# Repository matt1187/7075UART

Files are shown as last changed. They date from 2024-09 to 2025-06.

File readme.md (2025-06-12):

# Project  Solatron 7075 UART remote interface

History: Solartron 70755 GPIB Modul is useless (many people isn't capable to talking with GPIB modul) 
This is why, i make  MK-7075UART interface.
7075UART3
7075uart2

# PCB Revision History 
- MK-7075UART-000 improvement draft from  7075UART-000

# Feartures
- Talker/Listener mode
- Normal/exponent mode (10.123 VDC  / 1.0123E+1 VDC)
- 9600/38400/57600/115200 Baud select
- isolated RS232 interface
- SCPI & IEEE488.2 snytax 

# how to using of interface
- [howto (LINK)]

# Issues 
-  current no  remote function aviable

# Notes
- SSD1306 is optional. (actual firmware hasn't function for OLED)
- 74HCT165 on U11 is recommend,  (74LS165, you must modified PCB to adding of 1k Resistor on their output, otherwise, ISCP doesn't work)
- DC/DC converter should be soldered on bottom,  SW6 dip swith should attached with socket.
- U13, U14, U15 is optional (actual firmware doesn't support remote function, this ICs is for remote function )
- Diode D5 is recommend for pcb "engineering sample" for often reprogramming, while Solartron is turned off. Oterhwise, you can placed it with wire (or 0 ohm 2510 resistor)

# Bill of material
- [csv-file]
- [gerber-file]
- [3D-print-file]

# Firmware
- [atmega 8 firmware 0.5d]

# License
The project is free for non-commercial reproduction. Do not sell it on Ebay or other platforms for profit. Do not make a closed source derivative. Share your experiences and ideas with the community.

This work is licensed under a [Creative Commons Attribution-NonCommercial-ShareAlike 4.0 International License][cc-by-nc-sa].

[][cc-by-nc-sa]

[cc-by-nc-sa]: http://creativecommons.org/licenses/by-nc-sa/4.0/
[cc-by-nc-sa-image]: https://licensebuttons.net/l/by-nc-sa/4.0/88x31.png

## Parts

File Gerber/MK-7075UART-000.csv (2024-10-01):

Date: | Sa 14 Sep 2024 12:12:50 CEST
Tool: | Eeschema 6.0.11-2627ca5db0~126~ubuntu22.04.1
Component Count: | 66
Ref | Qnty | Value | Cmp name | Footprint | Supplier | Order-number
C1, C2, | 2 | 6p | C | Capacitor_SMD:C_0805_2012Metric | Mouser | 581-08055A6R0CAT2A
C3, C4, C5, C6, C7, C8, C10, C11, C12, C13, C14, C15, C20, C21, C22, C23, C24, C26, C27, | 19 | 100n | C | Capacitor_SMD:C_0805_2012Metric | Mouser | 581-08055C104K
C19, | 1 | 47µ 16V | C_Polarized | Capacitor_Tantalum_SMD:CP_EIA-6032-28_Kemet-C | Mouser | 80-T491C476M010
C25, C29, C30, | 3 | 10µ | C | Capacitor_SMD:C_0805_2012Metric | Mouser | 81-GRM21B71E106KE01L
C28, | 1 | 10n X2 | C | Capacitor_THT:C_Disc_D7.5mm_W5.0mm_P10.00mm | optional | optional
D1, D2, D3, D4 | 4 | 1N4818 | D | Diode_SMD:D_MiniMELF | Mouser | 637-LL4148
D5, | 1 | SHOTTKY | D | Diode_SMD:D_MELF | Mouser | 625-BYM13-40-E3/97 or 791-RMC1JPTE
F1, | 1 | RUEF90 | Polyfuse | Fuse:Fuse_Bourns_MF-RG300 | Mouser | 650-RUEF090
J1, | 1 | DB9_male_MountingHoles | DB9_Female_MountingHoles | Connector_Dsub:DSUB-9_Male_Vertical_P2.77x2.84mm_MountingHoles | Mouser | 649-D09P24A4GL00LF
J2, | 1 | ICSP | Conn_02x03_Odd_Even | Connector_PinHeader_2.54mm:PinHeader_2x03_P2.54mm_Vertical | Mouser | 571-5-146258-3
J4, | 1 | SSD1306 OLED Display | Conn_01x04_Female | Display:SSD1306 | don't place | don't place
JP3, | 1 |  | SolderJumper_2_Bridged | Jumper:SolderJumper-2_P1.3mm_Open_Pad1.0x1.5mm | don't place | don't place
L1, | 1 | L_Coupled_1243 | L_Coupled_1243 | Inductor_SMD:L_EPCOS_B82790 | Mouser | 871-B82790C225N265
Q1, | 1 | 16Mhz | Crystal | Crystal:Crystal_HC49-U_Vertical | Mouser | 815-ABL-16-B4Y
R1, R18, R19, | 3 | 1k | R | Resistor_SMD:R_0805_2012Metric | Mouser | 603-RC0805JR-071KL
R2, | 1 | 4.3k | R | Resistor_SMD:R_0805_2012Metric | Mouser | 603-RC0805JR-074K3L
R3, | 1 | 470 | R | Resistor_SMD:R_0805_2012Metric | Mouser | 603-RC0805JR-07470RL
R16, R17, | 2 | 392 | R | Resistor_SMD:R_0805_2012Metric | Mouser | 603-RC0201FR-07392RL
R20, R21, R22, R23, | 4 | 47k | R | Resistor_SMD:R_0805_2012Metric | Mouser | 603-RC0805JR-0747KL
SK1, | 1 | DB50_Male_MountingHoles | DB50_Male_MountingHoles-Connector | Connector_Dsub:DSUB-50-HD_Male_vertical | Mouser | 649-D50P24A4GL00LF
SW6, | 1 | config | SW_DIP_x04 | Package_DIP:DIP-8_W7.62mm | Mouser | 611-BD04AV
SW6-socket | 1 | config | SW_DIP_x04 | Package_DIP:DIP-8_W7.62mm | Mouser | 575-11041308410010
U1, | 1 | ATmega8-AU | ATmega8-AU-MCU_Microchip_ATmega | Package_QFP:TQFP-32_7x7mm_P0.8mm | Mouser | 556-ATMEGA8-16AU
U2, | 1 | 74LS164 | 74LS164-74xx | Package_SO:SOIC-14_3.9x8.7mm_P1.27mm | Mouser | 595-SN74LS164DR
U4, | 1 | 74LS157 | 74LS157 | Package_DIP:DIP-16_W7.62mm | Mouser | 595-SN74LS157N
U5, | 1 | 74LS189 | 74LS189-74xx | Package_DIP:DIP-16_W7.62mm | varios | SN74LS189
U8, | 1 | 74HCT00 | 74HCT00 | Package_SO:SOIC-14_3.9x8.7mm_P1.27mm | Mouser | 771-74HCT00D-T
U10, U11, | 2 | 74HCT165 | 74HCT165 | Package_SO:SOIC-16_3.9x9.9mm_P1.27mm | Mouser | 771-74HCT165D-T
U12, U13, U14, U15, | 4 | 74HCT595 | 74HCT595 | Package_SO:SOIC-16_3.9x9.9mm_P1.27mm | Mouser | 863-MC74HCT595ADG
U19, | 1 | IH0505S | IH0505S | Converter_DCDC:SIP-7 | Mouser | 710-177920514
U20, | 1 | MAX232A | MAX232 | Package_SO:SOIC-16_3.9x9.9mm_P1.27mm | Mouser | 511-ST3232EBDR or 700-MAX232ACWET
U21, U22, | 2 | HCPL-0600 | HCPL-0600 | Package_SO:SOIC-8_3.9x4.9mm_P1.27mm | Mouser | 630-HCPL-0600-000E

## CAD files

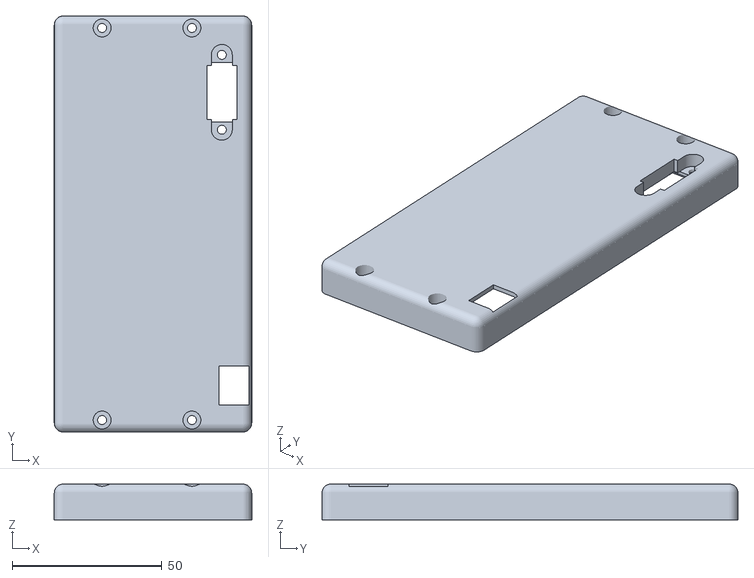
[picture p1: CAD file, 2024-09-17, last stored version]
top_wo_SCP.stl
66.0 x 139.0 x 12.0

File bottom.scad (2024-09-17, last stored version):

 $fn=32;
 
radius = 3; 
height=  12;
width = 66-radius-radius;
length = 123+16-radius-radius;


difference(){
translate([-3,-5,0])
   
    hull(){
            translate([0,0,0]){
            cylinder(r=radius,h=height+2);
            }
            translate([width,0,0]){
            cylinder(r=radius,h=height+2);
            }
            translate([0,length,0]){
            cylinder(r=radius,h=height+2);
            }
            translate([width,length,0]){
            cylinder(r=radius,h=height+2);
            }
        }
        
     //inner cutoff   
     translate([-0.5,-0.5,2])
        difference (){
        cube ([width+3.5, length-10+1,height]); 
     //DSUB 50 support
        cube ([20,74,4]);
     // below support       
        translate([54,26,0])
        cube ([10,123,height-2]); 
        translate([54,0,0])
        cube ([10,123,height-4]);     
      // rs232 support 
        translate([35,90,0])
        cube ([7,123,height-2]);         
        }
        
    //DSUB 50 cutoff   
        
    translate([9,6,0]){
    cylinder(r=4,h=4);
    cylinder(r=1.5,h=6);
    }       
      
    translate([9,6+61.1,0]){
    cylinder(r=4,h=4);   
    cylinder(r=1.5,h=6);   
    }   
    translate([9-13/2,6+(61.1-54)/2,0])
    cube ([13, 54,height]);
   
    translate([9-8/2,6,0])
    cube ([8, 61.1,4]);
    
    translate([1.5,6+(61.1-56)/2,5])
    cube ([15, 56,4]);
    
     // cutoff  for screw (rear of 7075)
    translate ([57,116,0])
    cylinder(r=4,h=3);
    
    translate ([-2.5,116,0])
    cylinder(r=4,h=3);
    
     // cutoff  for screw
    translate([-6,31,0])
    cube ([4, 10,height+2]);   
    
    // hole for screw 
    translate([10,-4,0])
    cylinder(r=1.5,h=20);   
    
    translate([10+30,-4,0])
    cylinder(r=1.5,h=20); 
    
    translate([10,-4+123+8,0])
    cylinder(r=1.5,h=20); 
    
    translate([10+30,-4+123+8,0])
    cylinder(r=1.5,h=20); 
  // hole for nuts  
   
    translate([10,-4,0])
    cylinder(r=3.3,h=5,$fn=6);  
     
    translate([10+30,-4,0])
    cylinder(r=3.3,h=5,$fn=6); 
    
    translate([10,-4+123+8,0])
    cylinder(r=3.3,h=5,$fn=6); 
    
    translate([10+30,-4+123+8,0])
    cylinder(r=3.3,h=5,$fn=6); 
    
   
        
    }

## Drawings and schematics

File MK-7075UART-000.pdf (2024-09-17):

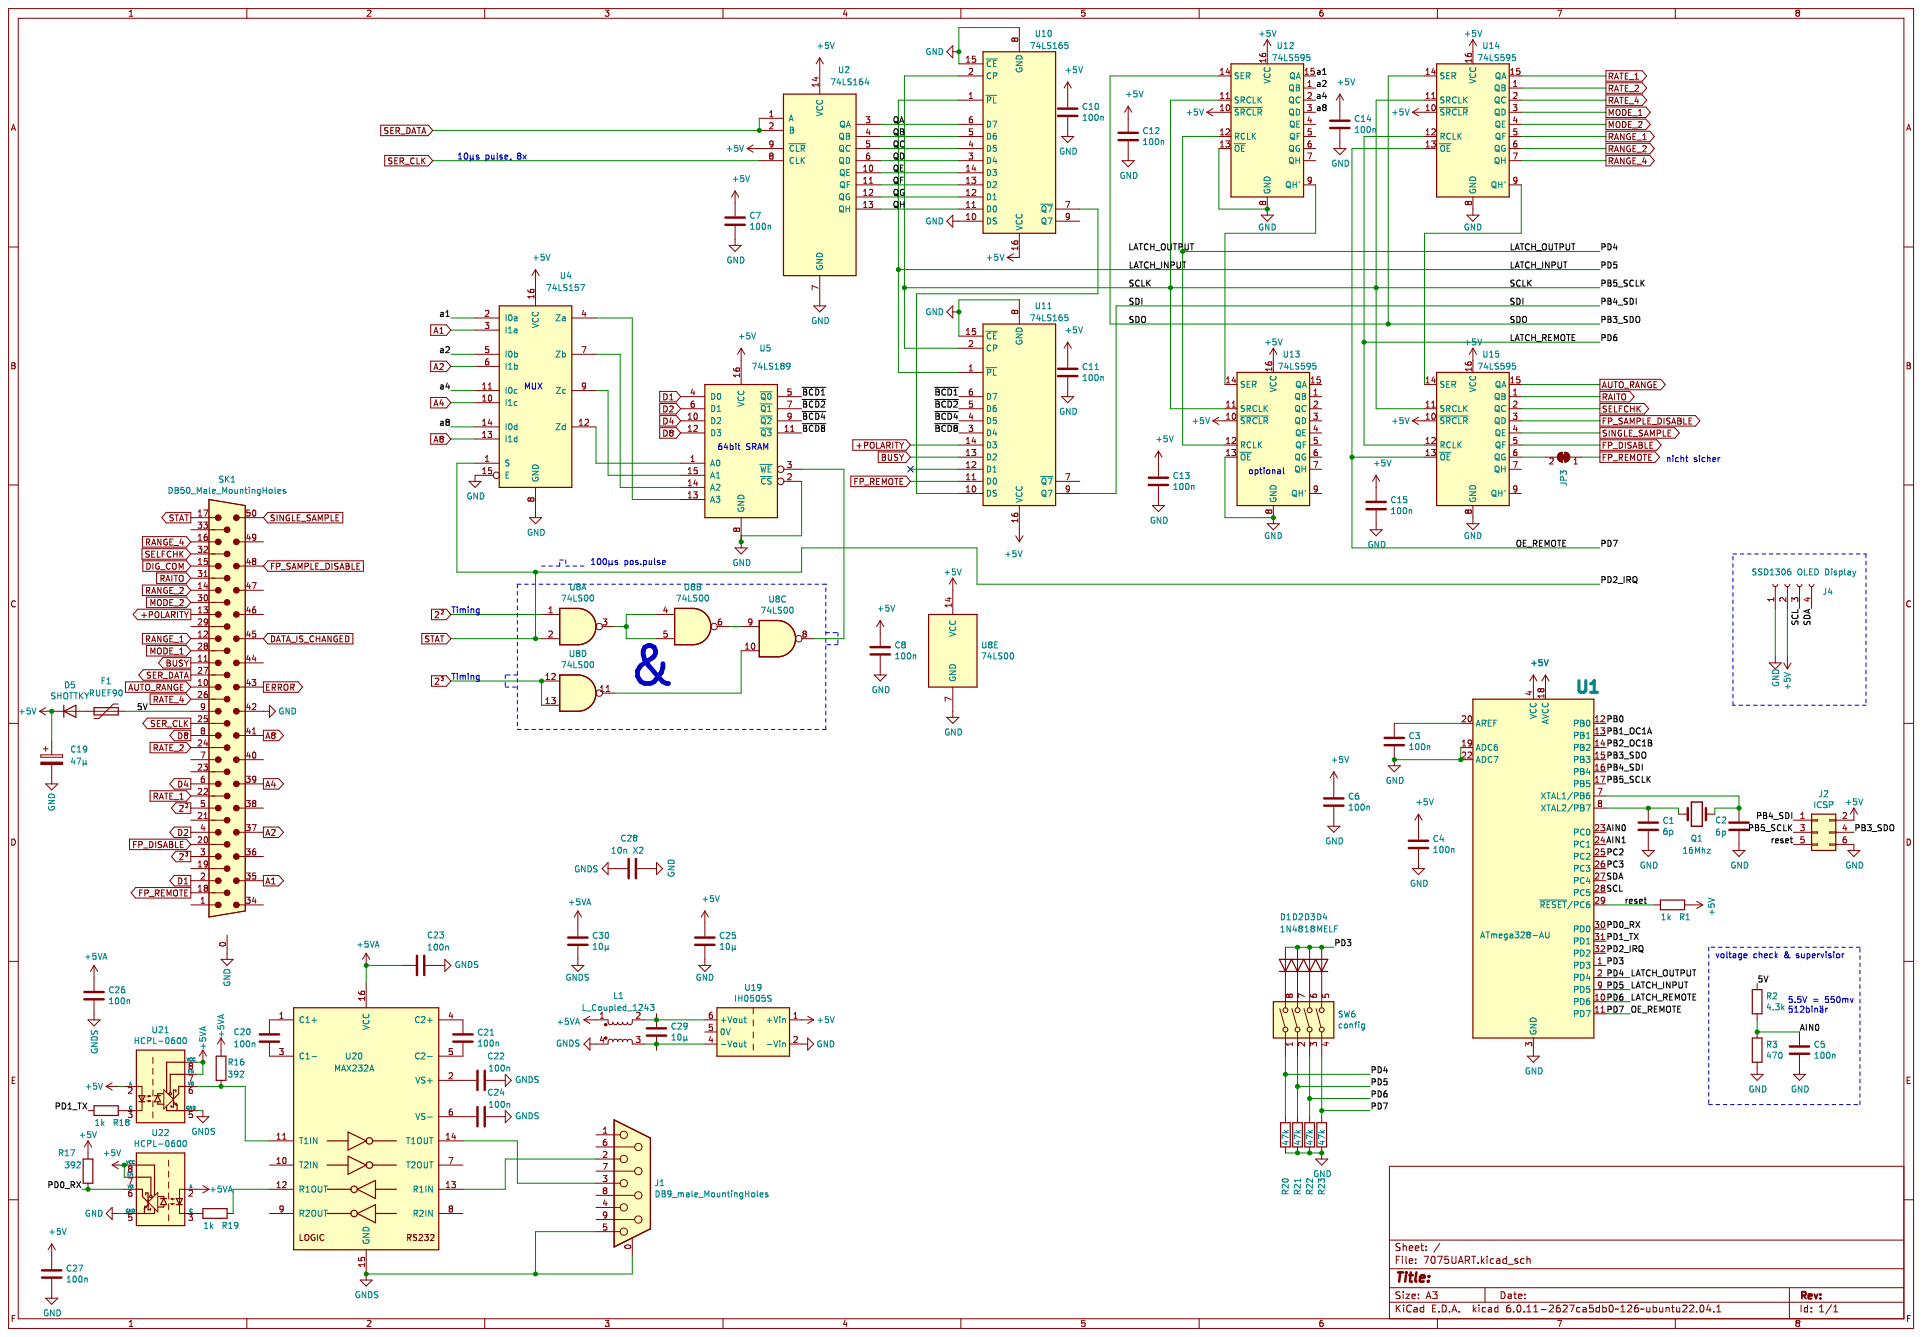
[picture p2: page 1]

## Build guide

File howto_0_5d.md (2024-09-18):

# HOW TO for  MK-7075UART Interface with Firmware 0.5d

*DIP Switch setting

DIP SW 1 & 2 
 - 00: BAUD 9600
 - 10: BAUD 38400
 - 01: BAUD 57600
 - 11: BAUD 115200

DIP SW 3
 - ON: Talker-mode: Interface send after evering measure cycle value
 - OFF: Listener-mode: Interface responds after commando.

DIP SW 4
 - ON:  Exponent Mode  "+1.0123E+1VDC"
 - OFF:  Normal-Mode  "+10.123VDC"

# SYNTAX

 - *IDN?  -  interface responds with "SOLARTRON 7075 UART 0.5d"
 - READ?  -  interface responds with actual measure value/data
